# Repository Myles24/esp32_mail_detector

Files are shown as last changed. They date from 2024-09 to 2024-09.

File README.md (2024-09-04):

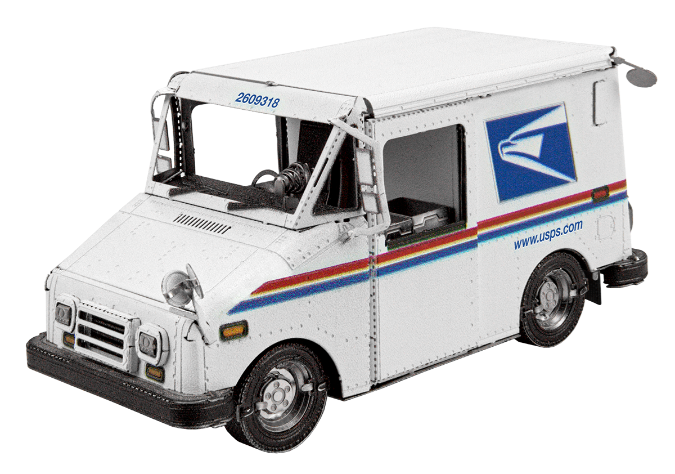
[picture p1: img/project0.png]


# Capstone Project

ESP32 Mail Alert System

# By Carson Alberding -- Computer Science Pathway

# Introduction

Hardware development based

Initially planned for research project

Breadboarding / circuit design

Worked with UD Computer Engineering professor [Dr\. Richard Martin](https://www.ece.udel.edu/people/faculty/rdmartin/)

Shifted project focus

# Problem & Initial Goals

Build some kind of device that detects when the mail comes

Audible/digital notification system

Attempted very briefly in the past with Raspberry Pi

Decided to take a different approach with the ESP32

Build a reliable and sustainable solution

Solar powered

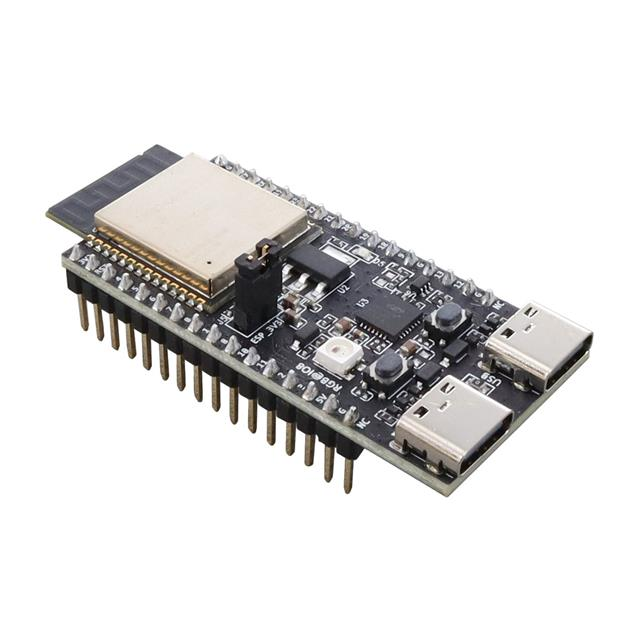
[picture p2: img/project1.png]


# ESP32

Low\-cost & low power WiFi\-enabled microcontrollers

Programmable through Arduino IDE \(C\+\+\)

Sensor control through GPIO pins

Can be easily powered by batteries or USB

Good fit for the project

# Materials

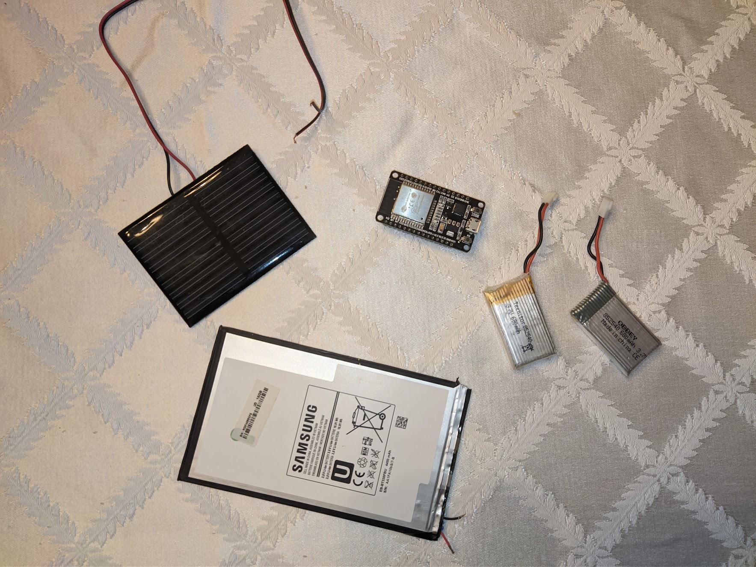
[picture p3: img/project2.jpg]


ESP32 dev board

Soldering stuff

Photoresistor

Wire

Battery

Multimeter

Solar Panel

Charging regulator

Voltage regulator

Raspberry Pi

Bluetooth Speaker

# Problem 1: WiFi

Needed to test whether the WiFi strength in the mailbox was sufficient

Using Arduino IDE\, coded simple wifi strength program  _\(Magdy\, n\.d\.\)_

Connected the ESP32 to laptop through USB to display results

Very poor wifi connection

Able to maintain connection \(possibly?\) but not establish a new one

Workable signal \-30dBm to \-85dBm

Results were in the \-90dBm range

Moving the router didn’t help

Making an antenna didn’t help

A lot of trial and error overall

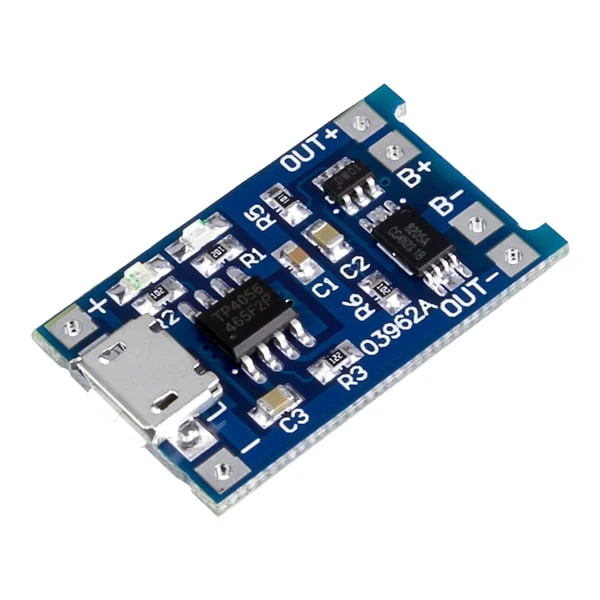
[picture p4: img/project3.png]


# Problem 2: Power

Initially planned to use 700mAh 3\.7v drone battery

Planned to use solar power to charge the battery

Bought TP4056 charging regulator  _\(Power ESP32\, n\.d\.\)_

Bought MCP1700 voltage regulator

Planned to use a feature called deep sleep on ESP32  _\(“Sleep\,” n\.d\.\)_

Active from 12:00 \- 4:30 PM each day\, sleep for the rest

Online sources stated that the ESP32 I had used <<1mA during deep sleep

Actually was about a 10mA draw in deep sleep

Assuming battery is at maximum capacity\, it would likely die in the span of 2 cloudy days

Low quality solar panel did not produce any substantial output with indirect sunlight

# Fixing Issues

Decided that a new ESP32 board was needed to potentially fix these issues

After a bit of research\, I decided to get the much newer ESP32\-c6  _\(“ESP32\-C6\,” n\.d\.\)_

Hoping that it resulted in improved wifi strength and lower sleep power consumption

Didn’t want to bank on the lower power consumption\, so I bought better solar panels

Tried to test if charging was working each day that I could

Putting 2 solar panels in parallel would double the current output

When I got the new ESP32\, I measured <0\.1mA current when sleeping

When it was on\, current was between 30\-40 mA and ~10mA less when wifi was off

WiFi seemed to be better as well inside the house\, with a 10dBm increase in signal

Critical problems seemed to be fixed \-\- for now

# Charging Setup

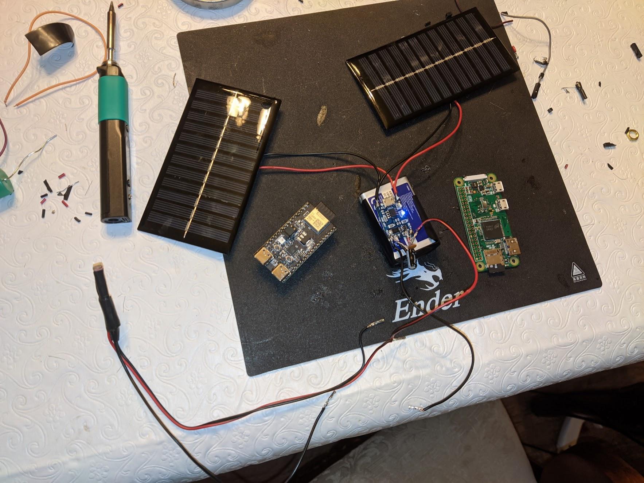
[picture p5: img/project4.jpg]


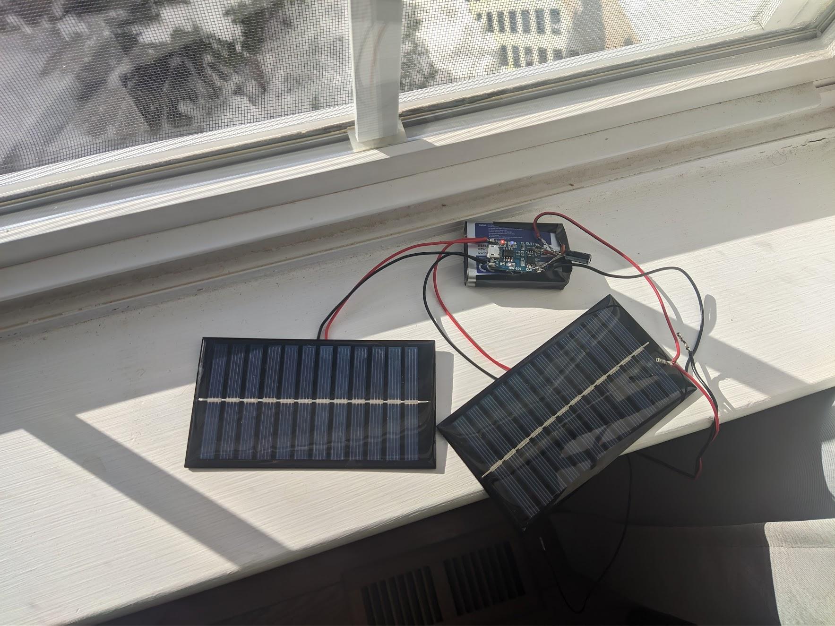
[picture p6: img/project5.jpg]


# Coding

With most of the hardware issues figured out\, it was time to start coding the actual software

Planned to use a photoresistor as the sensor\, so one of the GPIO pins on the ESP32 could read it

Needed to design the code around the fact that deep sleep reruns the code from the beginning

Designed to be ran at any time of day or night

Reduce power consumption by limiting its active hours and WiFi usage

# Code Overview: Setup Method

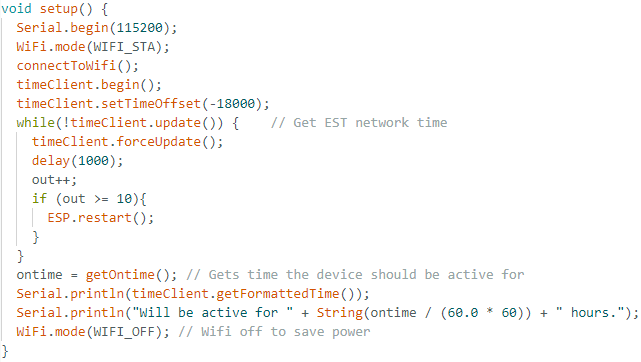
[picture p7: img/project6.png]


# Code Overview: Loop Method

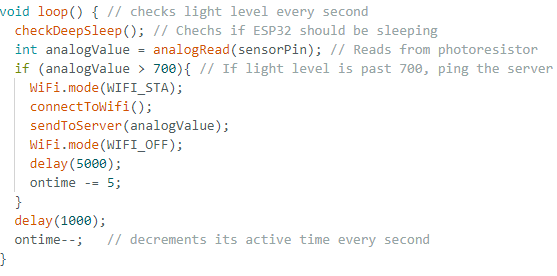
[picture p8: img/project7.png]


# Code Overview: Time methods

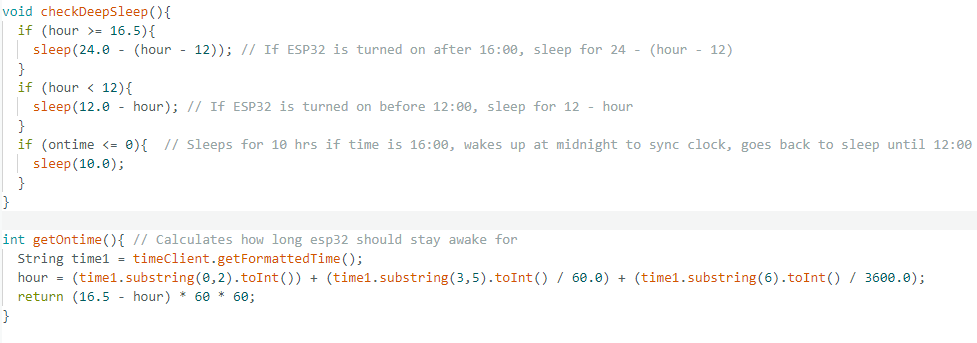
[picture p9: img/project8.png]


# Mounting the Device

<span style="color:#000000"> __Outside the Mailbox__ </span>

<span style="color:#000000"> __Inside the Mailbox__ </span>

| Pros<br /><br />No waterproofing<br />Concealed<br /> | Cons<br /><br />Poor WiFi connection<br />Takes up space<br />Build a hidden setup |
| :-: | :-: |

| Pros <br /><br />Reliable WiFi<br />Easier wiring setup<br /><br /><br /><br /><br /><br /><br /> | Cons<br /><br />Waterproofing<br />Hard to access components<br />Finite space<br />Looks ugly |
| :-: | :-: |

# Optimal Solution

Since the mailbox post it sat on was vinyl\, I figured it must be hollow inside

Prying it open revealed a large\, hollow space for all the electronics

No weatherproofing required

Plastic interior resulted in a reliable WiFi connection

Drilled a small hole for wires to pass through

Mounted 2 solar panels with strong double faced tape S & E facing

Routed the photoresistor setup though a small hole in the back corner of the mailbox

Covered all wires and openings with white tape

Ensured that the ESP32 was in an accessible location

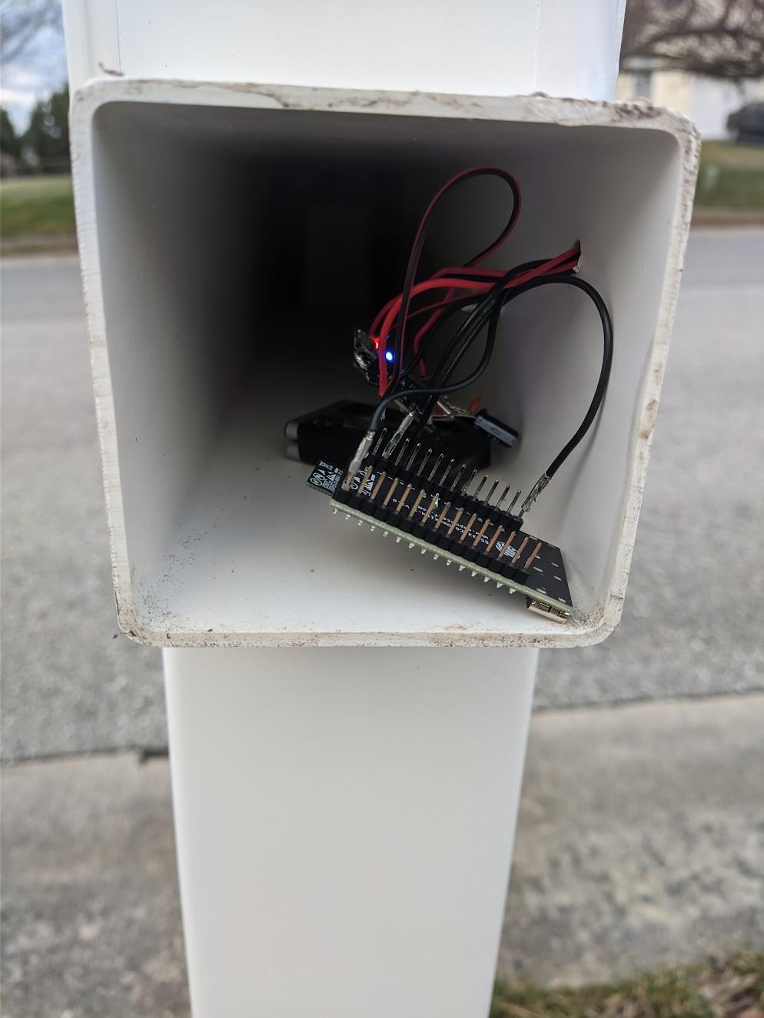
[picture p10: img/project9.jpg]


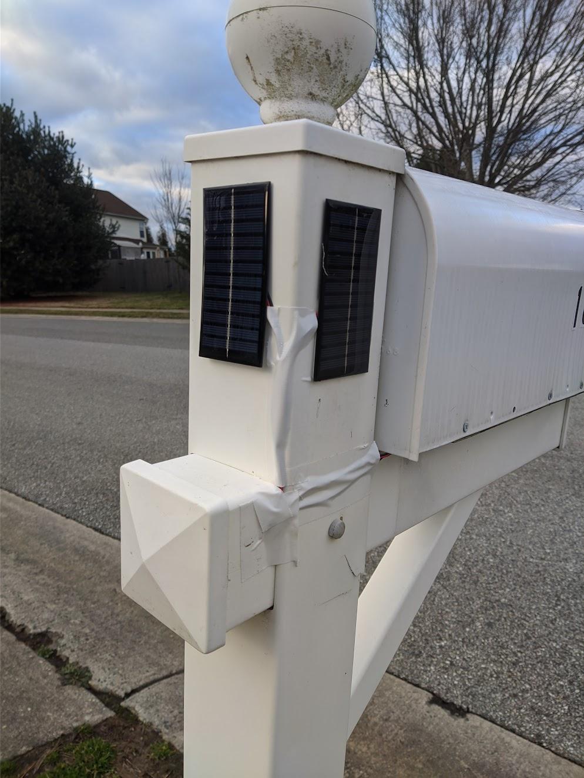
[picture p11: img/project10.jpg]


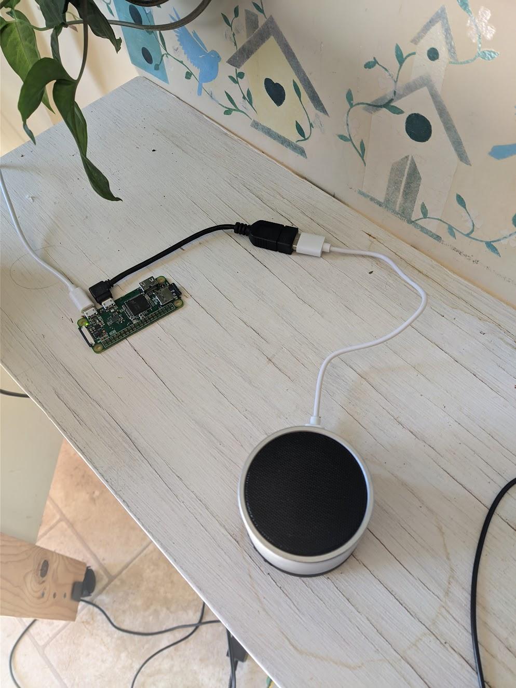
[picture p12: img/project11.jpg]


# Server Setup

NodeJs would be easy enough to set up and has a bunch of libraries and support

Decided to go with the Raspberry Pi zero to run the server

Server will be constantly listening for anything sent to it

Was able to connect with a bluetooth speaker to play the sound

Created a linux service to pair with speaker on boot

Used PM2 to automatically start the server on boot  _\(“Running Node”\, 2023\)_

# Server Code

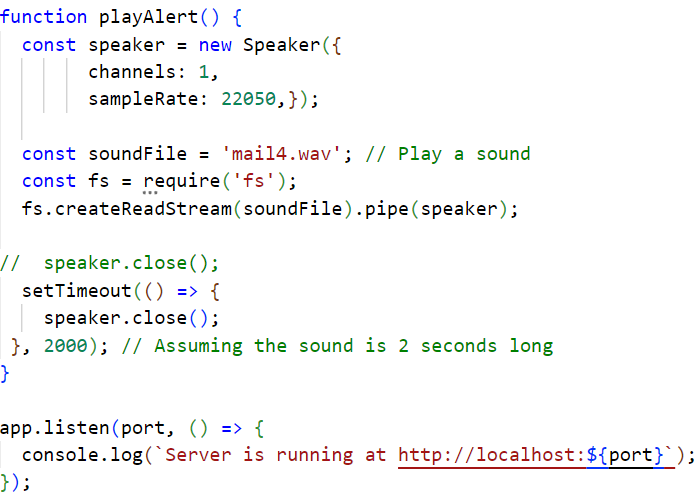
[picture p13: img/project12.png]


# Initial Results

The device worked\, but only some of the time

I would open the mailbox 4 times to test it\, but the notification would only sound twice

It would stop functioning after a day or two and had to manually reset

It seemed like the device was freezing somehow

The battery and solar setup was working great; no power issues

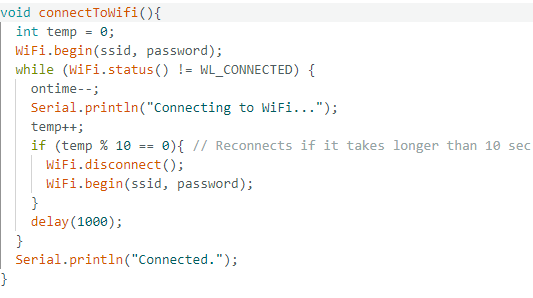
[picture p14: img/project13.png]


# Debugging

Trying to figure out what was wrong over the next few weeks

Hard to iterate on since I would have to wait long periods of time

It was clear that it would stop functioning after a sleep cycle

Was working fine when I reset it during the day

I changed the variable type for the amount of time it sleeps for

Added a timeout for connecting to wifi and fetching the network time

Changed the format of the audio file it played so it worked every time

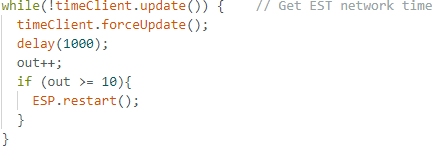
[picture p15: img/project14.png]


# Reflection

Overall\, the project was a success

Developed a working prototype that functioned as intended

A lot more involved than I originally thought

Many little issues added up

Good learning experience

Glad I was able to make something actually helpful

Appreciate the guidance given by my mentor

# Resources

<span style="color:#000000"> _Power ESP32/ESP8266 with Solar Panels and Battery_ </span>  <span style="color:#000000">\. \(n\.d\.\)\. Random Nerd Tutorials\. Retrieved April 6\, 2024\, from </span>  _[https://randomnerdtutorials\.com/power\-esp32\-esp8266\-solar\-panels\-battery\-level\-monitoring/](https://randomnerdtutorials.com/power-esp32-esp8266-solar-panels-battery-level-monitoring/)_

<span style="color:#000000"> _Sleep Modes \- ESP32\-C6 \- — ESP\-IDF Programming Guide v5\.2\.1 documentation_ </span>  <span style="color:#000000">\. \(n\.d\.\)\. Technical Documents\. Retrieved April 6\, 2024\, from </span>  _[https://docs\.espressif\.com/projects/esp\-idf/en/stable/esp32c6/api\-reference/system/sleep\_modes\.html](https://docs.espressif.com/projects/esp-idf/en/stable/esp32c6/api-reference/system/sleep_modes.html)_

<span style="color:#000000">Magdy\, K\. \(n\.d\.\)\. Get ESP32 WiFi Signal Strength \(Arduino\) & RSSI Value\. DeepBlue\. Retrieved April 6\, 2024\, from </span>  _[https://deepbluembedded\.com/esp32\-wifi\-signal\-strength\-arduino\-rssi/](https://deepbluembedded.com/esp32-wifi-signal-strength-arduino-rssi/)_

<span style="color:#000000">ESP32 HTTP GET and HTTP POST with Arduino IDE\. \(n\.d\.\)\. Random Nerd Tutorials\. Retrieved April 6\, 2024\, from </span>  _[https://randomnerdtutorials\.com/esp32\-http\-get\-post\-arduino/](https://randomnerdtutorials.com/esp32-http-get-post-arduino/)_

<span style="color:#000000">Running Node\.js Apps with PM2 \(Complete Guide\)\. \(2023\, October 25\)\. Better Stack\. Retrieved April 9\, 2024\, from </span>  _[https://betterstack\.com/community/guides/scaling\-nodejs/pm2\-guide/](https://betterstack.com/community/guides/scaling-nodejs/pm2-guide/)_

<span style="color:#000000">ESP32\-C6 Wi\-Fi 6 & BLE 5 & Thread/Zigbee SoC\. \(n\.d\.\)\. Espressif Systems\. Retrieved April 10\, 2024\, from </span>  _[https://www\.espressif\.com/en/products/socs/esp32\-c6](https://www.espressif.com/en/products/socs/esp32-c6)_

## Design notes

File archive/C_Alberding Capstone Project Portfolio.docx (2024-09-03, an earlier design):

Project Goal: Demonstrate how computer technology evolved by illustrating how computing systems work at a fundamental level with integrated circuits and microprocessors, and how those concepts are still integral for practical purposes today.

This project will consist of three parts that will all illustrate essential factors of computing.

## Part 1: Integrated Circuits

Goal: Show how computers work at a fundamental level by building circuits using concepts of logic gates and decoders

### Project 1: 4-bit adder using logic gates

A 4-bit adder is an important circuit in computer engineering because it forms the fundamental building block for arithmetic operations in digital systems.

Logic gates are fundamental building blocks in digital circuit design and form the basis of digital electronics. They are elementary circuits that perform logical operations on binary inputs (0s and 1s) and produce a binary output. These gates are essential in constructing more complex digital systems, such as microprocessors, memory units, and other digital devices.

In this circuit, 5 logic gate chips will be used, each gate providing two inputs and one output:

OR Gate: If one or more inputs are set to HIGH, the output will be set to HIGH.

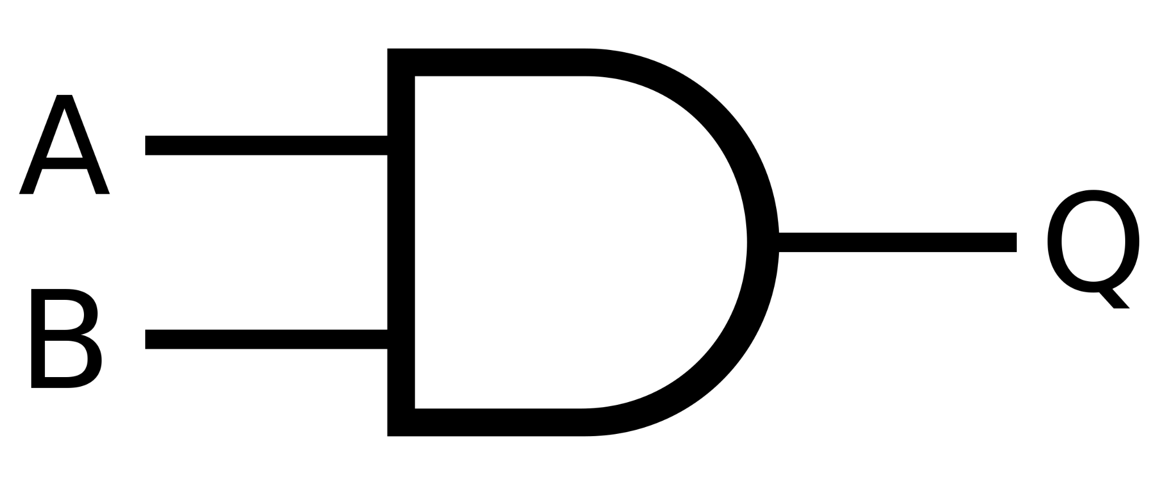
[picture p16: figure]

AND Gate: If both inputs are set to HIGH, the output will be set to HIGH.

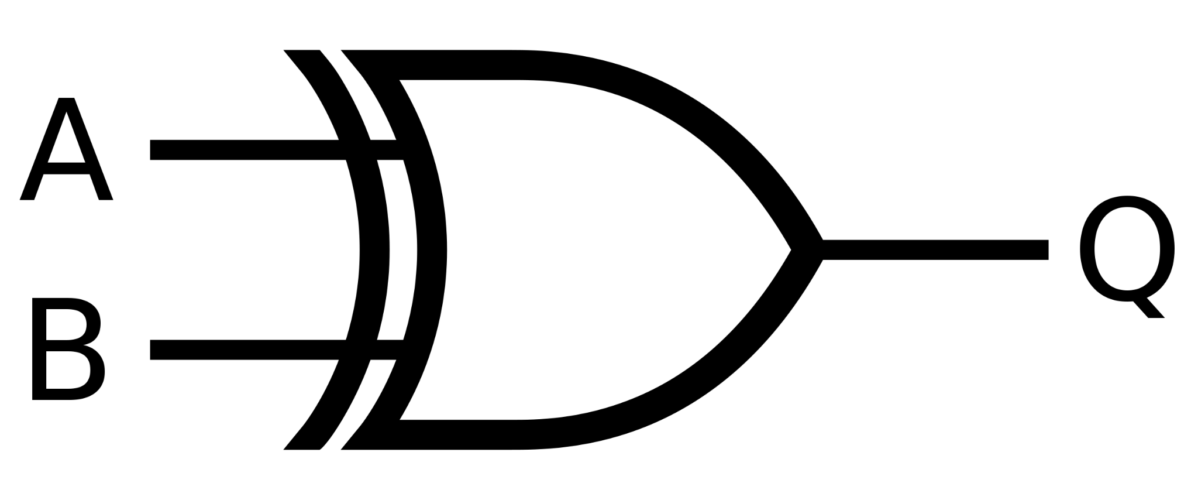
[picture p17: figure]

XOR Gate: Output will be set to HIGH if one input is set to HIGH, but not both.

By arranging these gates in a specific order, we can create a circuit that can add two sets of “4-bits” with carry.

In total, 8 XOR gates and AND gates are needed, and 4 OR gates are needed. Each chip has 4 gates, so a total of 5 chips.

The chips that I used are as follows:

OR Gate: SN74LS32N (x1)

AND Gate: SN7408N (x2)

XOR Gate: CD4070B (x2)

Click here (https://drive.google.com/file/d/1dEILSuByVKMZO4pGnVvcIlrdTd_EvQve/view?usp=sharing) for a detailed view of the schematic

The 4000 series of ICs are pretty outdated nowadays, and probably shouldn’t be used in this circuit due to interference caused by the wiring, but it’s just what was on hand.

Datasheets, and more specifically, the pinouts of these chips are always useful tools to look at when designing a circuit. Understanding the pinout allows you to identify which pins are the inputs and outputs.

Reading the pinouts of these chips, we can design a circuit using the schematic above.

Click here (https://drive.google.com/file/d/17UMDmhc-LQQwTCrDNKWY9ZC3C6-fQQrF/view?usp=sharing) for a detailed view of the schematic

After building the circuit and testing it, we can see that it does function properly. On the left-hand side, the first 4 DIP switches are set to 1001, or 9 in decimal. The next 4 dip switches are set to 0100, or 4 in decimal. On the right-hand side, the output is sent to the LEDs which display 01101, or 13 in decimal, the sum of 9 and 4.

Click here (https://drive.google.com/file/d/1erWKNuYXhdPsFsg6MtxhsMan7me8Ixbn/view?usp=sharing) for a more detailed view of the image

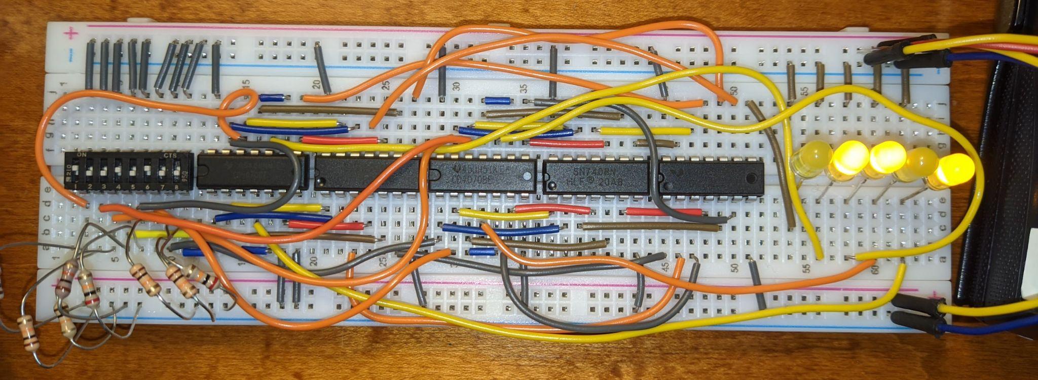
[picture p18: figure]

## Part 3: Modern Microcontrollers

Goal: Demonstrate how today’s microcontrollers utilize these computing concepts for a variety of practical purposes through programmability and ease of use and implementation.

### Project x: Mail Detector

Project Goal: Utilize an ESP32 microcontroller with light/motion sensor to detect when mailbox is opened. The project will be solar-powered and transmit data to Node.js server running from a raspberry pi.

Parts / Logistics:

- Esp32 microcontroller
- Solar panel
- Charging regulator
- Voltage regulator
- LiPo Battery
- Charging circuit design
- Raspberry Pi
- Arduino & Nodejs code
- Light/motion sensor (PCB???)

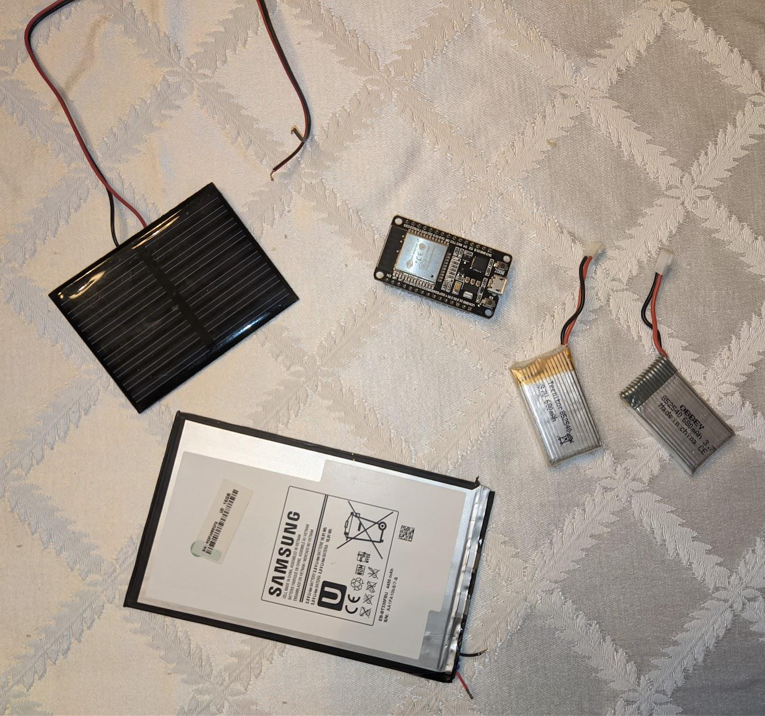
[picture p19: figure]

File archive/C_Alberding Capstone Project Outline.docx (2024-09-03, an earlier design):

Project Goal: Demonstrate how computer technology evolved by illustrating how computing systems work at a fundamental level with integrated circuits and microprocessors, and how those concepts are still integral for practical purposes today.

This project will consist of three parts that will all illustrate essential factors of computing.

## Part 1: Integrated Circuits

Goal: Show how computers work at a fundamental level by building circuits using concepts of logic gates and decoders

Subgoals:

- Build experience with circuit design
- Demonstrate designs visually and mathematically

Plans / Ideas:

- Explain a series of logic gates through a variety of circuits
- 4-bit adder
- 7-segment display decoder

Complete by 1/1/2024

## Part 2: Microprocessors & EEPROMS

Goal: Illustrate how microprocessors and interface adapters utilize fundamental computing concepts at a much more compressed and efficient form factor through programmability.

Subgoals:

- Gain more experience with assembly language
- Demonstrate how programming can be implemented and how it became widely more efficient
- Explain how the systems outlined in Part 1 are becoming a lot more conceptual
- Display interactions between both hardware and software
- Show how ease of implementation is on the rise

Plans / Ideas:

- Explain how the 65C02 Microprocessor is efficient at managing the complexity of a design
- Show through programming how rewritable EEPROMS replace the need for combinational logic by implementing the same designs from Part 1
- Use the concepts outlined in Part 1 to build more complex programs

Complete by 1/1/2024

## Part 3: Modern Microcontrollers

Goal: Demonstrate how today’s microcontrollers utilize these computing concepts for a variety of practical purposes through programmability and ease of use and implementation.

Subgoals:

- Gain experience with programming microcontrollers (C++)
- Show how microcontrollers (like the Arduino) are designed to serve numerous purposes and are made easier to use and implement due to object-oriented programming
- Build a device to serve a practical purpose

Plans / Ideas:

- Custom PCB Shield for arduino (KiCAD)
- https://jlcpcb.com/
- Mail detector

Mail Detector

Overall Goal: Utilize an ESP32 microcontroller with light/motion sensor to detect when mailbox is opened. The project will be solar-powered and transmit data to Node.js server running from a raspberry pi.


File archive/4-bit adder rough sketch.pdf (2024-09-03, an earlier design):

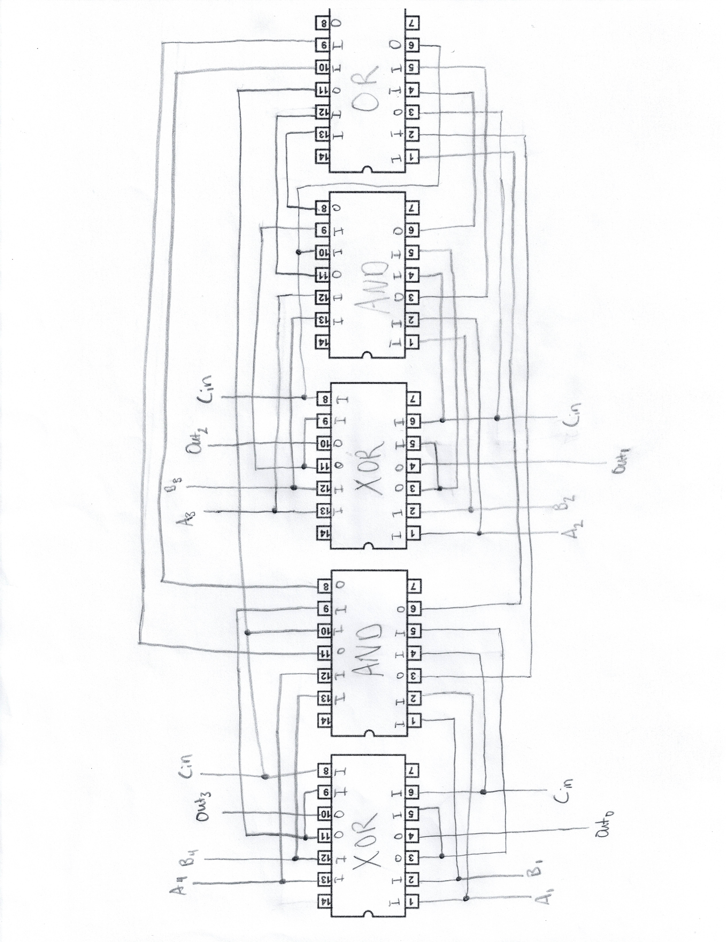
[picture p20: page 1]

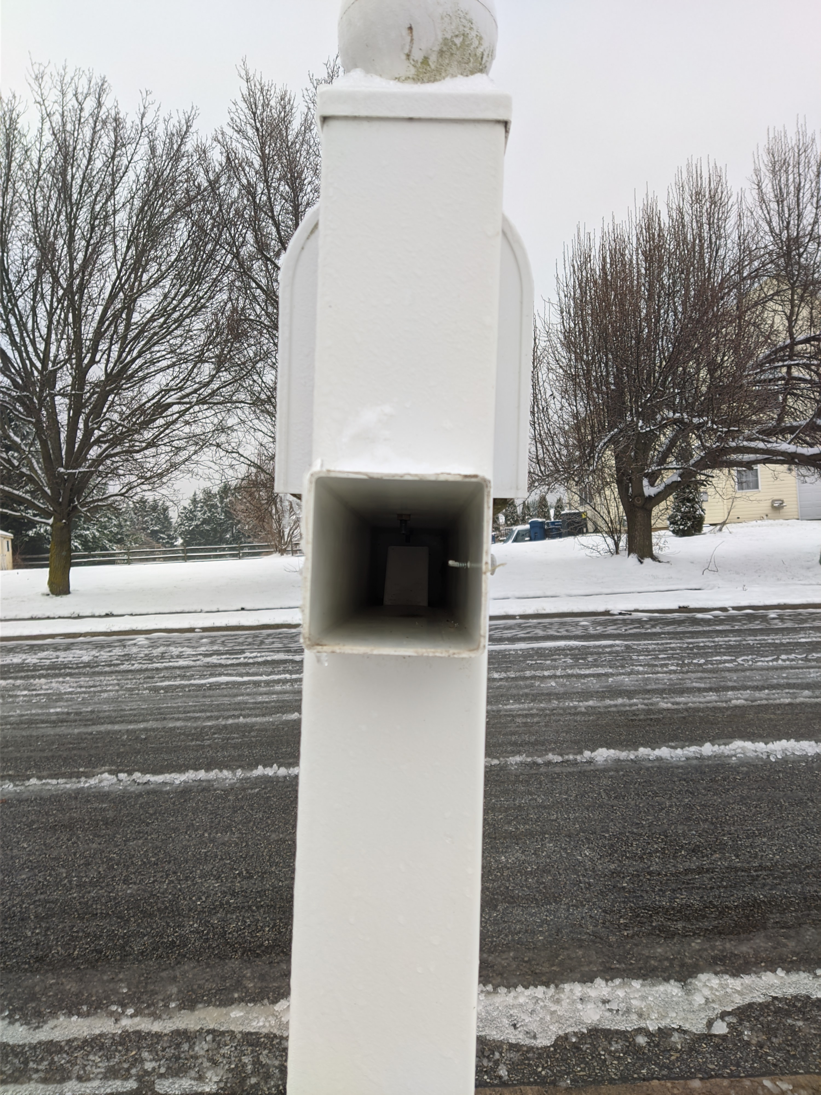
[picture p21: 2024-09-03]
mailbox location.jpg

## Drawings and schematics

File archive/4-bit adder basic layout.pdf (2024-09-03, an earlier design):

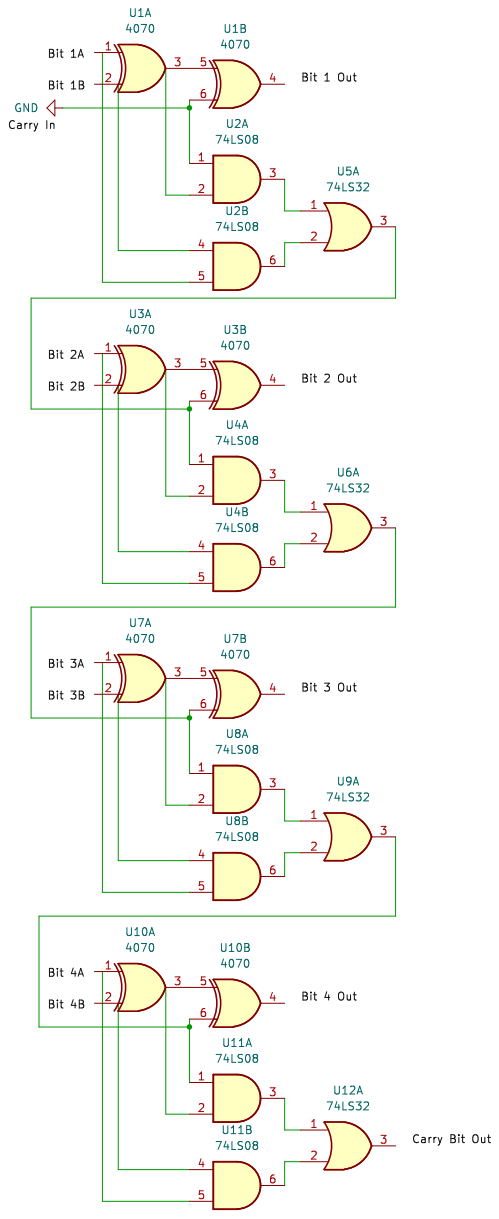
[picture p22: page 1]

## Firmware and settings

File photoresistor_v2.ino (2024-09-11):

#include <WiFi.h>
#include <HTTPClient.h>
#include <esp_sleep.h>
#include "time.h"
#include <NTPClient.h>
#include <WiFiUdp.h>

const char *ssid = "xxxxxxxxxxxxxxx";
const char *password = "xxxxxxxxxxxxx";
const char* ntpServer = "pool.ntp.org";

const int sensorPin = 2;
String timeStamp;

WiFiUDP ntpUDP;
NTPClient timeClient(ntpUDP);

int out = 0; // timeout counter for updating time

double hour = 0; // current time displayed as a single hour
int ontime = 0;

void setup() { 
  Serial.begin(115200);
  WiFi.mode(WIFI_STA); 
  connectToWifi();
  timeClient.begin();
  timeClient.setTimeOffset(-18000); 
  while(!timeClient.update()) {    // Get EST network time
    timeClient.forceUpdate();
    delay(1000);
    out++;
    if (out >= 10){
      ESP.restart();
    }
  }
  ontime = getOntime(); // Gets time the device should be active for
  Serial.println(timeClient.getFormattedTime());
  Serial.println("Will be active for " + String(ontime / (60.0 * 60)) + " hours.");
  WiFi.mode(WIFI_OFF); // Wifi off to save power
}

void loop() { // checks light level every second
  checkDeepSleep(); // Chechs if ESP32 should be sleeping
  int analogValue = analogRead(sensorPin); // Reads from photoresistor
  if (analogValue > 700){ // If light level is past 700, ping the server
    WiFi.mode(WIFI_STA);
    connectToWifi();
    sendToServer(analogValue);
    WiFi.mode(WIFI_OFF);
    delay(5000);
    ontime -= 5;
  }
  delay(1000);
  ontime--;   // decrements its active time every second 
}


void checkDeepSleep(){
  if (hour >= 16.5){
    sleep(24.0 - (hour - 12)); // If ESP32 is turned on after 16:00, sleep for 24 - (hour - 12)
  }
  if (hour < 12){
    sleep(12.0 - hour); // If ESP32 is turned on before 12:00, sleep for 12 - hour
  }
  if (ontime <= 0){  // Sleeps for 10 hrs if time is 16:00, wakes up at midnight to sync clock, goes back to sleep until 12:00
    sleep(10.0);
  }
}

int getOntime(){ // Calculates how long esp32 should stay awake for 
  String time1 = timeClient.getFormattedTime();
  hour = (time1.substring(0,2).toInt()) + (time1.substring(3,5).toInt() / 60.0) + (time1.substring(6).toInt() / 3600.0);
  return (16.5 - hour) * 60 * 60;
}

void sleep(double hrs){ // Sleep method for a number of hours
  uint64_t microseconds = hrs * 3600 * 1000000;
  Serial.println("Going to sleep for " + String(hrs) + " hours; "+ String(microseconds));
  delay(100);
  esp_sleep_enable_timer_wakeup(microseconds);
  esp_deep_sleep_start();
}

void connectToWifi(){
  int temp = 0;
  WiFi.begin(ssid, password);
  while (WiFi.status() != WL_CONNECTED) {
    ontime--;
    Serial.println("Connecting to WiFi...");
    temp++;
    if (temp % 10 == 0){ // Reconnects if it takes longer than 10 sec
      WiFi.disconnect();
      WiFi.begin(ssid, password);
    }
    delay(1000);
  }
  Serial.println("Connected.");
}

void sendToServer(int32_t rssi) { // Sends photoresistor value to server 
  HTTPClient http;

  String url = "http://192.168.1.182:3000/storeSignalStrength?rssi=" + String(rssi);

  http.begin(url);
  int httpCode = http.GET();

  if (httpCode > 0) {
    Serial.printf("[HTTP] GET... code: %d\n", httpCode);
  } else {
    Serial.printf("[HTTP] GET... failed, error: %s\n", http.errorToString(httpCode).c_str());
  }

  http.end();
}
